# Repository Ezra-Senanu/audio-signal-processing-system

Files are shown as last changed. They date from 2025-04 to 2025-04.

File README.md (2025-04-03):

# Audio Signal Processing System – Treble & Bass Control, Mixer, and Microphone Preamp

## Project Overview

This project implements an Audio Signal Processing System designed to process audio signals with dynamic equalization features such as treble and bass control, as well as mixing multiple audio inputs and amplifying microphone signals. The goal of this project is to provide precise tonal adjustments, combine multiple audio sources with minimal distortion, and amplify microphone inputs with clear signal integrity.

### Key Features:
- **Treble and Bass Control**: Dynamic audio equalization for tonal adjustments.
- **Mixer Circuit**: Combines multiple audio signals while minimizing distortion.
- **Microphone Preamp Circuit**: Amplifies microphone signals for optimal gain control.
- **PCB Design**: Optimized for minimal interference and efficient power distribution.
- **SPICE Simulation**: Validates and optimizes frequency response and circuit behavior.

## Project Components

1. **Treble and Bass Control Circuit**  
   - Designed to adjust the high and low frequencies of the audio signal for dynamic sound shaping.

2. **Mixer Circuit**  
   - Combines multiple audio signals while maintaining signal integrity and minimizing distortion.

3. **Microphone Preamp Circuit**  
   - Amplifies microphone signals for optimal clarity and gain control, ensuring high-quality audio capture.

4. **PCB Design & Layout**  
   - Designed and routed using Altium, ensuring minimal interference and optimal signal quality.
  
5. **Simulation**  
   - SPICE simulations performed in Altium to validate circuit performance and optimize frequency response.

## How It Works

1. **Audio Signal Input**: The audio signals (e.g., from an audio source or microphone) are input into the system.
2. **Treble & Bass Adjustment**: The treble and bass control circuit allows the user to adjust the tonal balance of the audio signal.
3. **Mixing**: The mixer combines multiple audio signals into one, maintaining a clear and balanced output.
4. **Amplification**: The microphone preamplifier amplifies any microphone input signals to a suitable level.
5. **Output**: The final mixed and amplified audio signal is output to speakers or recording devices.

## Getting Started

### Prerequisites:
- **Hardware**:  
  - Audio source(s) (e.g., microphone, line-in signals)
  - Amplification components
  - PCBs and components for assembly (Altium files available)
  
- **Software**:  
  - **Altium Designer**: For PCB design and SPICE simulation.
  - **Embedded Systems IDE**: For firmware development and system integration.

###Altium Project
  -Link
  ```bash
   https://365.altium.com/files/4EA10067-0436-4EB5-9764-D52401654ED2

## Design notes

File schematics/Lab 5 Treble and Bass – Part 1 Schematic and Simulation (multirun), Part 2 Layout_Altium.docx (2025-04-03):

Brigham Young University - Idaho

ECEN 299 – Lab 5

Treble and Bass – Part 1 Schematic and Simulation, Part 2 Layout

7/12/2024

Table of Figures

# Lab 5 (Part 1)

Objectives

Design a PCB for the treble & bass equalization circuits for your stereo amplifier system. Prepare Gerber files to be sent to a PCB manufacturer for fabrication. Later in the semester, when the prototypes arrive, you will be prepared to pick components for your circuit and easily measure the circuit’s performance.

# Principles to Be Studied

- Altium simulation and layout software
- Techniques to simplify debugging.

# Background

Most stereo systems have some sort of equalization, with a tone control adjustment for bass, treble, and perhaps a few mid-band adjustments as well. The design for this lab will allow you to boost (amplify) or cut (attenuate) the bass and treble frequencies by selecting specific capacitor values that allows you to control at what frequency to start boosting or cutting. Although there are many companies to choose from, we will likely use JLCPCB. JLCPCB is a manufacturer in China. You can get good quality boards for a very low price.

# Available Components

Item | Mft Part No. | Manufacturer | Description
1 | LF347DT | STMicroelectronics | IC QUAD OPAMP JFET 4MHZ 14SOIC
2 | 929834-01-36-RK | 3M | CONN HEADER 36POS SNGL .100 STR
3 | Miscellaneous capacitors/resistors, sizes 0603 – 1206

Table 1: Available Components

# Procedures

Figure 1 shows the overall configuration of the stereo system you are currently developing. It includes the left and right channels with the bass and treble filter circuits you are designing in this lab.

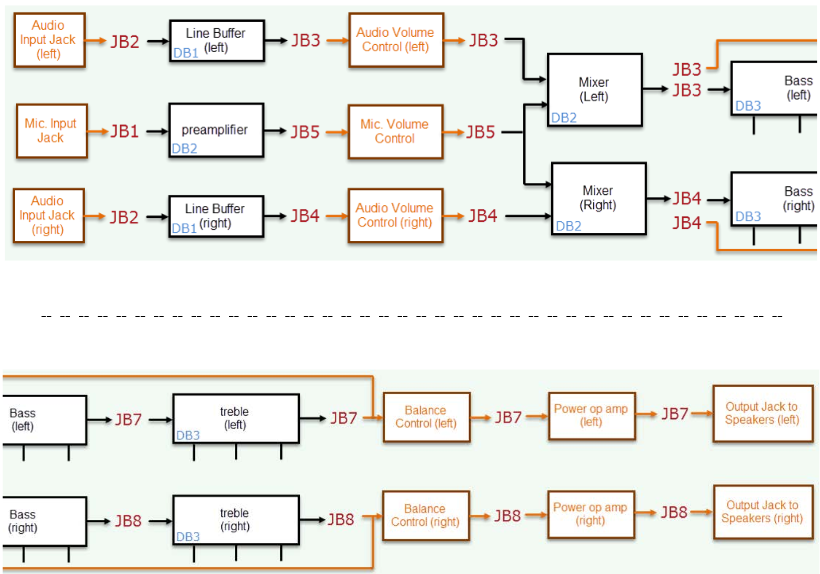
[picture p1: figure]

Figure 1 – Stereo System (Right and Left Channel) Block Diagram Redo Checkmarks.

1. Create a new project in your shared workspace titled Lab5_TB_Lxx_yyy where xx is your lab bench number and yyy are your initials. If you need to review how to do this see lab 4 instructions.
2. Ensure that your projects share dialog box looks like this. See lab 4 instructions or the apendix if you get stuck.

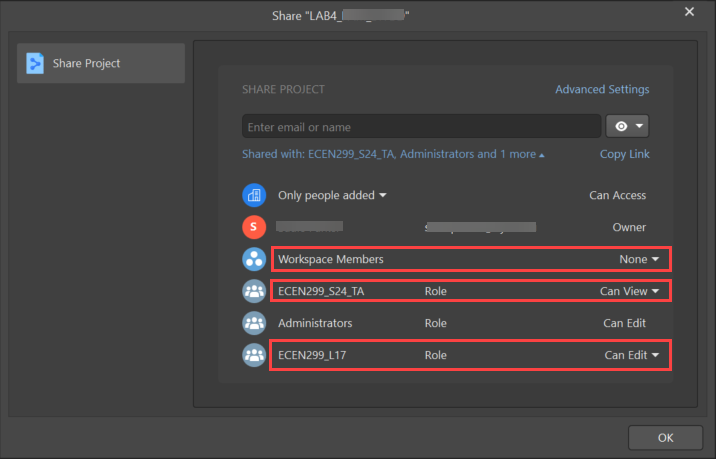
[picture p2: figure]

3. Now just like you did for lab 4, go ahead and create a schematic sheet and PCB Layout Document. Keep the correct name scheme for both documents (Lab5_Sheet1.SchDoc and Lab5_PCB1.PcbDoc)
4. Ensure everything is saved locally and to the Server (look for the green check mark specified in lab 4)

# Create a Symbol for the 23 Pin Header

These instructions are pretty much identical to the lab 4 instructions but the names, number of pins, and footprint will be different.

1. Select Panels > Project (if not already open).
2. Right click Project Group 1.DsnWrk.
3. Select Add Existing Project.
4. Browse to C:\Users\<…>\Desktop\ECEN299\ECEN299_Library
5. Select ECEN299_Library.LibPkg.
6. Select Open.
7. Double click on ECEN_Library.SchLib.
8. Select Panels > SCH Library.
9. Select Add.
10. Type ‘23 Pin Header’ for the Design Item ID.
11. Click OK.
12. In the SCH Library Panel, select 23 Pin Header.
13. Select Tools > Symbol Wizard.
14. Enter 23 for the Number of Pins.
15. Select ‘Single in-line’ as the Layout Style.
16. Enter the pin names in the Display Name column and select the Electrical type as per the figure below.

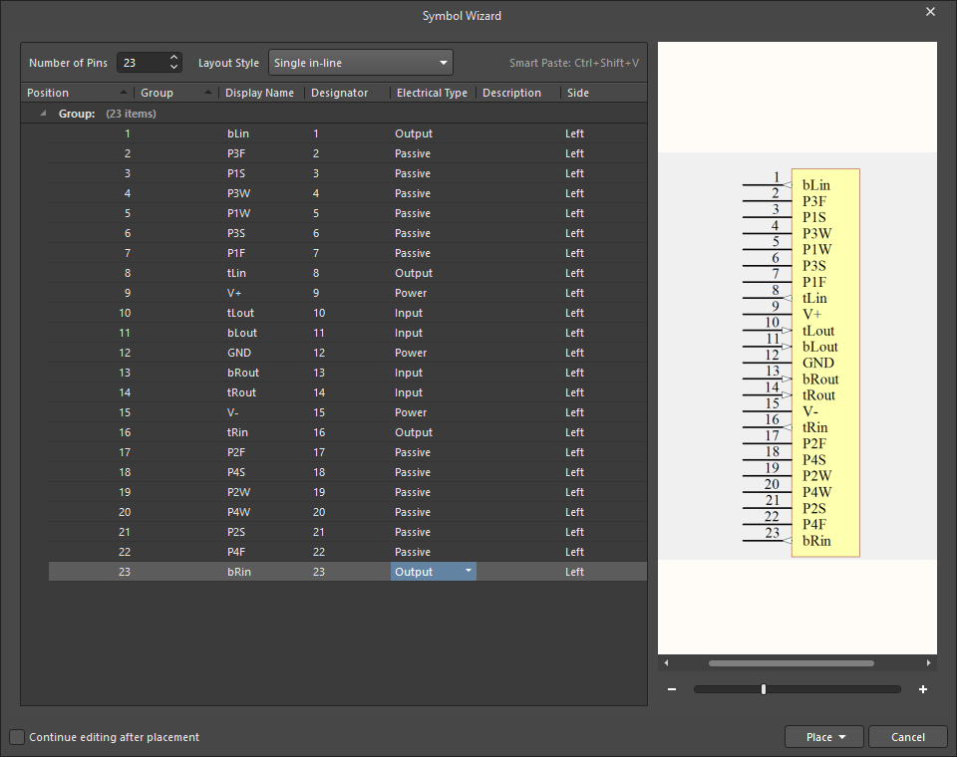
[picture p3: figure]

17. Select Place > Place Symbol.
18. In the Properties window, under Parameters, ensure that 'Footprints' is selected (highlighted in blue), then click on Add... > Footprint.
19. Click on Browse and select KBS_23pin_Header_TB_EQ.

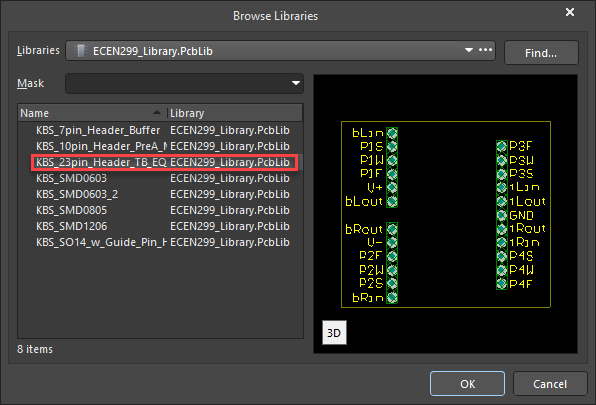
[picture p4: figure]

20. Select OK.
21. Select Pin Map and verify accuracy. (Make sure to verify all 23 pins match!)
22. Select OK to close Model Map
23. Select OK to close PCB Model.
24. In the Properties window, under Parameters, click on Add... > Simulation.
25. Select 'Browse' and locate your DONOTHINGSPICEMODEL.CIR file, which was created in Lab 2 (refer to Lab 2 if needed). Then select Open and OK.
26. In the Projects Window, right click ECEN299_Library.SchLib and select Save.
27. Right click ECEN299_Library.LibPkg and select Compile Integrated Library…
28. Save your Project.
29. In panels navigate to SCH Library. You should now see the 23 Pin Header included among the other Design Item ID’s shown here.

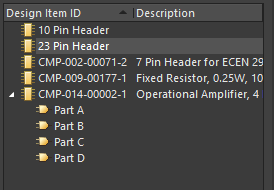
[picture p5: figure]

# Create a Symbol for the Capacitors

1. Select Panels > SCH Library.
2. Select Add.
3. Type CMP-Capacitor for the Design Item ID
4. Click OK.
5. Double-click on CMP-Capacitor to open its properties if they are not already open.
6. In the Properties panel, set the following settings as shown below.

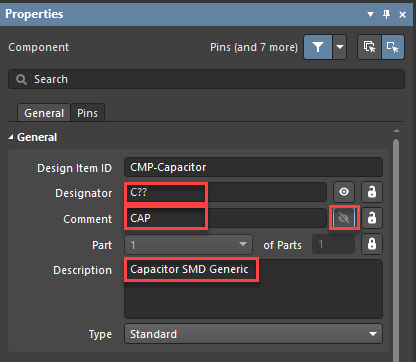
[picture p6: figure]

7. Press the g key to cycle through grid spacing. Stop on Grid: 10mil. To see the current grid spacing look at the bottom left of the program.
8. Select Place > Pin.
9. Press the ‘Tab’ key to change the properties of the pin.
10. Set the following properties as shown below for the first pin.

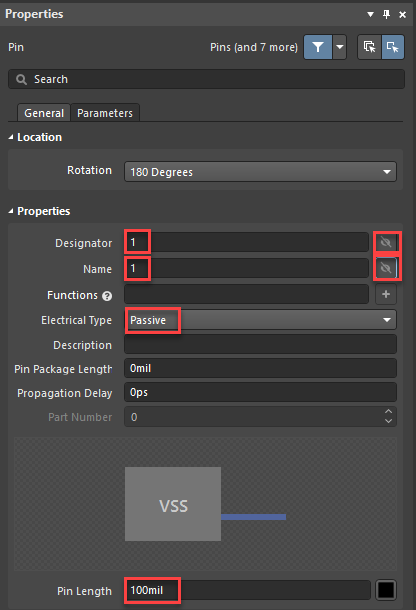
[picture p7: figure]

11. When placing the pin, ensure the designator points outward from your symbol, as it will be used to connect your capacitor to other components/sources.
12. Place the first pin at X: -100mil and Y: 0mil.
13. Place the second pin at X: 200mil and Y: 0mil (Note: you will need to flip the pins orientation to point the designator outwards).
14. Right click to exit placing a pin. Select Place > Line.
15. Press the ‘Tab’ key to change the properties of the Line.
16. Change the line color to blue.

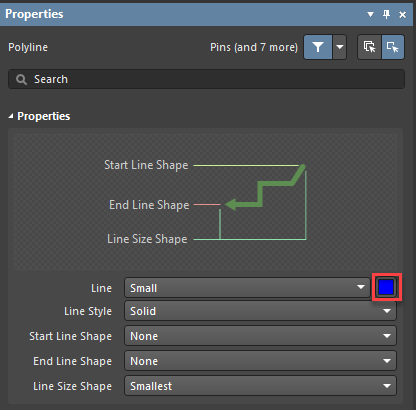
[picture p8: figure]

17. Click the Pause button in the middle of the screen.
18. Start drawing a horizontal line from X: 0 mil, Y: 0 mil to X: 30 mil, Y: 0 mil.
19. Then, draw a vertical line from Y: 80 mil to Y: -70 mil at X: 30 mil.
20. Draw another horizontal line from X: 100 mil, Y: 0 mil to X: 70 mil, Y: 0 mil.
21. Then, draw another vertical line from Y: 80 mil to Y: -70 mil at X: 70 mil.
22. Then, select SCH Library > CMP-Capacitor
23. If the Properties panel is not opened for the CMP-Capacitor, select Panels > Properties.
24. Next, choose Add... > Parameter.
25. Double-click 'Parameter' and rename it to 'Value.'
26. Double-click '*' and set the capacitor's default value to 3.3n.
27. Make the value visible by clicking on the eye icon.
28. Click on Add… > Footprint.
29. Click on Browse and select KBS_SMD0603
30. Select OK.
31. Repeat steps 27 to 29 to add the KBS_SMD0805 and KBS_SMD1206 footprints.
32. Select Add… > Simulation.
33. Select 'Capacitor' for the Model Type.
34. Select OK.
35. In the Projects Window, right click ECEN299_Library.SchLib and select Save.
36. Right click ECEN299_Library.LibPkg and select Compile Integrated Library…

## Designing the Treble and Bass

Figures 2 and 3 illustrate one channel of the bass and treble filter circuits you will design and implement in your stereo amplifier system. You will need to duplicate the circuits in both figures for the left and right channels. Ensure that every resistor, potentiometer, and capacitor has a unique designator.

Note that bLpot and tLpot, Fig. 2 and Fig. 3, are located on the chassis but you need them for simulation purposes.

1. To get the potentiometer, select Components > Simulation Generic Components. Then look for potentiometer in the search field.

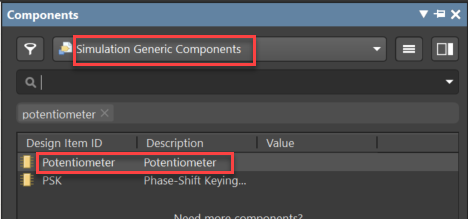
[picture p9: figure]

2. In the Properties panel of the potentiometer, rename the Designator field as needed (e.g., bLpot for the bass left channel) and set the value to 10k, matching the potentiometers already mounted in your chassis.

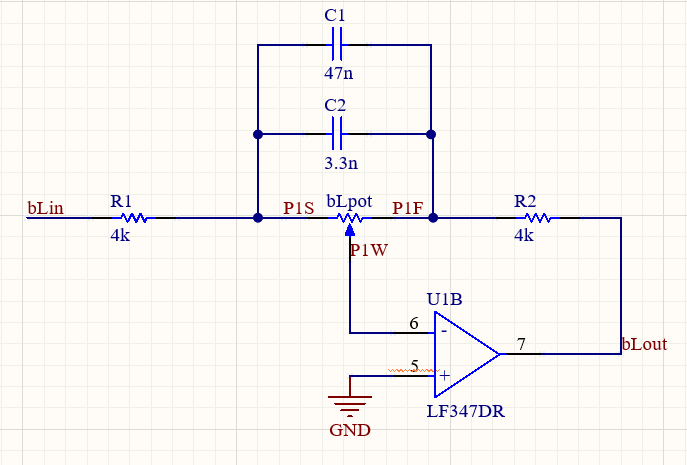
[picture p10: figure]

Figure 2 – Bass Tone Control (one channel)

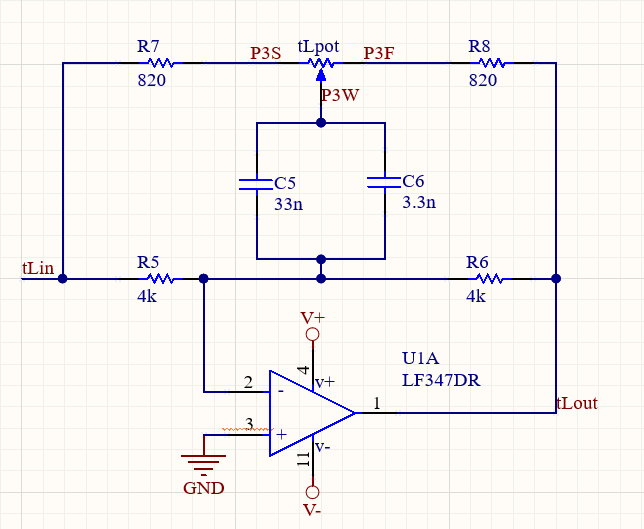
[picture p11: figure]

Figure 3 – Treble Tone Control (one channel)

Table 2 provides the signal names and pin numbers for the 23-pin header. Be careful to label your nets correctly. Miss labeled nets is one of the most common problems in layouts.

Table 2 Signal Names and Pin numbers for the 23-pin header.

Signal Name | Pin # | Description
bLin | 1 | Left channel Bass input
bRin | 23 | Right channel Bass input
P1S | 3 | Source impedance side pot terminal for bass (L)
P2S | 21 | Source impedance side pot terminal for bass (R)
P1W | 5 | Wiper terminal for bass pot (L)
P2W | 19 | Wiper terminal for bass pot (R)
P1F | 7 | Feedback impedance side pot terminal for bass (L)
P2F | 17 | Feedback impedance side pot terminal for bass (R)
P3S | 6 | Source impedance side pot terminal for treble (L)
P4S | 18 | Source impedance side pot terminal for treble (R)
P3W | 4 | Wiper terminal for treble pot (L)
P4W | 20 | Wiper terminal for treble pot (R)
P3F | 2 | Feedback impedance side pot terminal for treble (L)
P4F | 22 | Feedback impedance side pot terminal for treble (R)
bLout | 11 | Left channel Bass output
bRout | 13 | Right channel Bass output
tLin | 8 | Left channel Treble input
tRin | 16 | Right channel Treble input
tRout | 14 | Right channel Treble output
tLout | 10 | Left channel Treble output
V+ | 9 | Positive power rail
V- | 15 | Negative power rail
GND | 12 | Ground

## PCB Tester Compatibility

Verify that your design is compatible with the PCB Tester that was created at BYU-Idaho that can check for shorts and opens in your PCB after it is fabricated. To be compatible with the tester, assign the op amps in your circuit using the instructions in Fig 4.

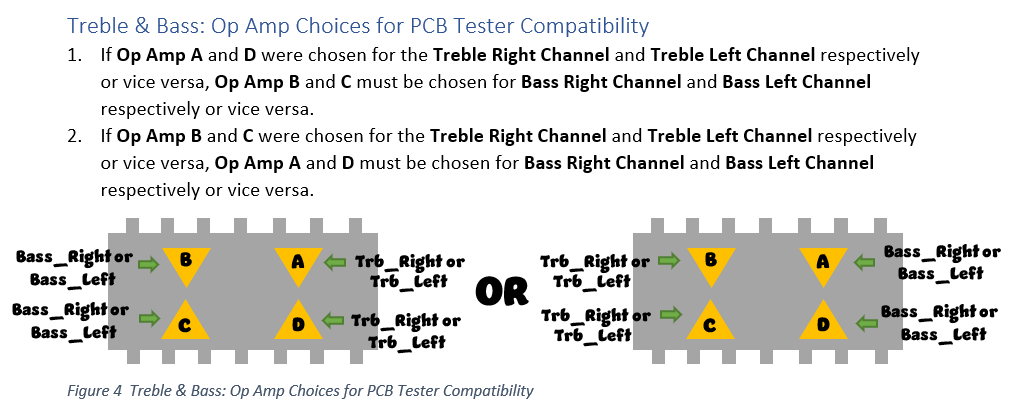
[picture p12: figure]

Figure 4 – Op Amp Selection Guild for compatibility with PCB Tester

# Calculate Expected Bass and Treble Gains

The circuit design allows you to either boost or cut low or high frequencies within the audible range. Let’s calculate the expected gain for both the bass and treble circuit at low and high frequencies and for the control knobs turned all the way down and all the way up.

When analyzing the potentiometer in the context of the circuit, you need to split it into separate resistors, as shown in Fig. 5. The value of α corresponds to the wiper position within the potentiometer. When α=1 , the knob is turned fully clockwise. When α=0 , the knob is turned fully counterclockwise. When α=0.5 , the knob is at the center position.

Figure 5 – Equivalent Potentiometer Circuit

# Bass

The gain equation (also called the transfer function H(jω)=V_(out) /V_(in) ) for the bass circuit and components values needed to meet the design specifications are shown in Appendix A. Using Appendix A Summary and Worksheet, evaluate the gain of the circuit at ω→0 and ω→∞ with the potentiometer set position at α=0 (cut) and α=1 (boost) and record these values in Table 3. Note that at these two frequencies, the capacitor impedance can be replaced with either an open ( ω→0 ) or short ( ω→∞ ) circuit.

Table 3 Bass Filter Circuit Frequency Response Calculations.

|H(jω)|=(ω_n)/(ω_d)(√(1+(ω/(ω_n))^2))/(√(1+(ω/(ω_d))^2)) | ω→0 | ω→∞
α=0 | |H(jω)|_(α=0, ω=0) = | |H(jω)|_(α=0, ω=∞) =
α=1 | |H(jω)|_(α=1, ω=0) = | |H(jω)|_(α=1,ω=∞)

|H(jω)|_(dB) =20log_10 |H(jω)| | ω→0 | ω→∞
α=0 | |H(jω)|_(dB) = | |H(jω)|_(dB) =
α=1 | |H(jω)|_(dB) = | |H(jω)|_(dB) =

How does this analysis support the claim that the circuit will act as a bass tone control?

Use the component values derived in Appendix A. The potentiometer R_2 =10 kΩ is already mounted in your chassis. Simulate this circuit in Altium Designer to verify that you get the desired frequency response.

## Simulate the Circuit

1. Create two DC sources into your schematic: one set at +14 volts and the other at -14 volts to supply power to the Op-Amp.
2. Add a Sinusoidal source to bLin with an AC Magnitude of 1 V.

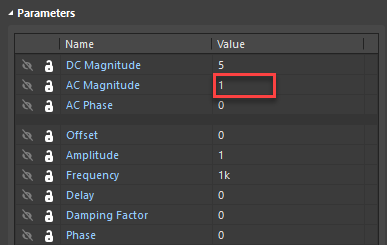
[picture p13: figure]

3. Select Simulate > Simulation Dashboard.
4. To set up parametric sweep for the bLpot potentiometer, select Sweep and then click on Settings.
5. Enter the following Sweep parameters values:
6. Select OK.
7. Create a Frequency Analysis by expanding the AC Sweep section.
8. Set Start Frequency to 20 and End Frequency to 20k.

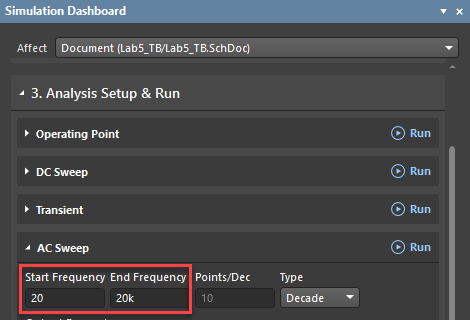
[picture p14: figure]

9. Add bLout as your Output Expression. Ensure the complex functions are set to Magnitude (dB) as shown below when adding the output expression.
10. Select Create.
11. Select Simulate > Run Simulation
12. In the Top Menu, select Simulate > Generate Netlist.
13. Find the Sweep line:
14. Modify the line to add [position] after bLpot.

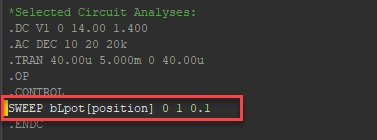
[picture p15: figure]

15. Select Simulate > Run. If it does not open, check Panels > Messages for any error messages.

Figure 6 and Figure 7 plot the typical frequency responses you can achieve with this circuitry. Each curve in the plot represents a different setting of the bass or treble control. Notice that they can be set for a flat (no boost or cut) response.

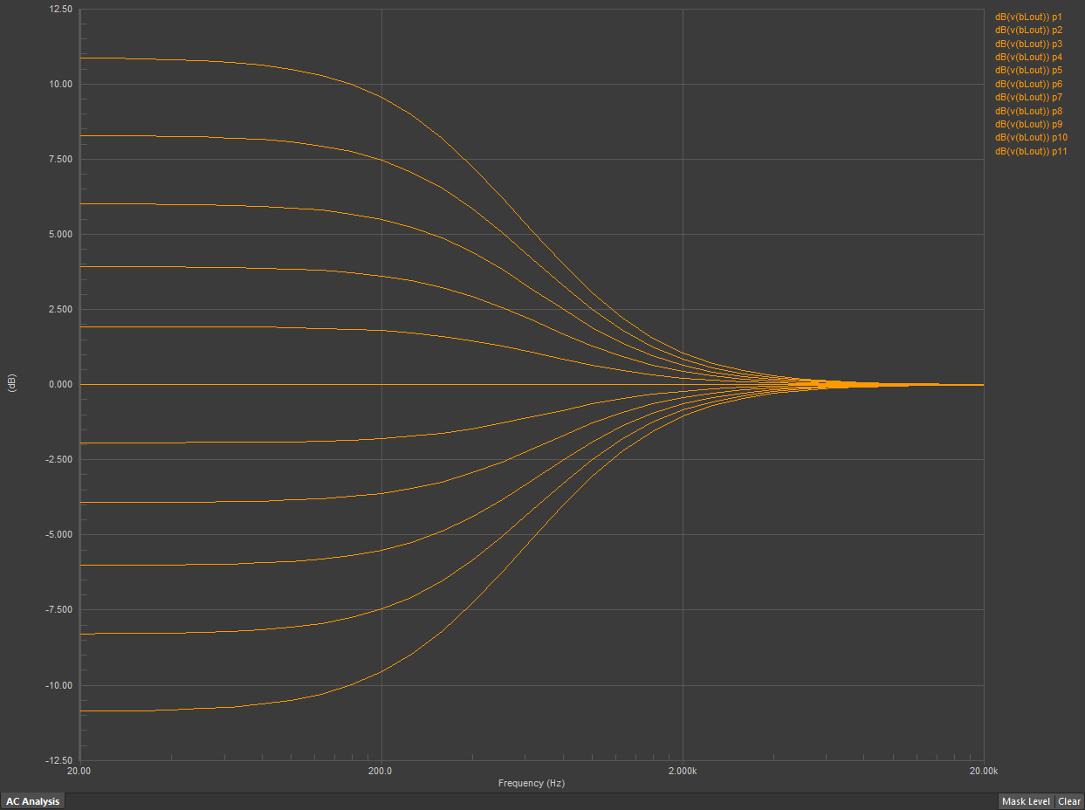
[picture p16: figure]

Figure 6 – Bass Control Frequency Response

# Treble

We will now develop a more detailed analysis of the circuit performance that will help us complete the design. For a maximum boost setting, A_v =1 when ω→∞ and A_v ≫1 when ω→0 .

The gain equation (also called the transfer function H(jω)=V_(out) /V_(in) ) for the treble circuit is shown in Appendix B and is derived by using KCL to sum the currents into each of the potentiometer nodes.

Using Appendix B Summary and Worksheet, evaluate the gain of the treble circuit at ω→0 and ω→∞ with the potentiometer set position at α=0 (cut) and α=1 (boost) and record your results in Table 4. At these two frequencies, the capacitor impedance can be replaced with either an open ( ω→0 ) or short ( ω→∞ ) circuit.

Table 4 Treble Filter Circuit Frequency Response Calculations.

|H(jω)|=(|1+(jω)/(ω_n)|)/(|1+(jω)/(ω_d)|)=(√(1+(ω/(ω_n))^2))/(√(1+(ω/(ω_d))^2)) | ω→0 | ω→∞
α=0 | |H(jω)|_(α=0, ω=0) = | |H(jω)|_(α=0, ω=∞) =
α=1 | |H(jω)|_(α=1, ω=0) = | |H(jω)|_(α=1, ω=∞) =

|H(jω)|_(dB) =20log_10 |H(jω)| dB | ω→0 | ω→∞
α=0 | |H(jω)|_(dB) = | |H(jω)|_(dB) =
α=1 | |H(jω)|_(dB) = | |H(jω)|_(dB) =

How does this analysis support the claim that the circuit will act as a treble tone control?

## Simulate the Circuit

You will now simulate this circuit in Altium Designer to verify that you get the desired frequency response.

1. Add a Sinusoidal source to tLin with an AC Magnitude of 1 V
2. Delete the previous Output Expression (dB(v(bLout)).
3. Add tLout as your Output Expression. Ensure the complex functions are set to Magnitude (dB).
4. Change the Sweep Parameter from bLpot to tLpot as shown below.

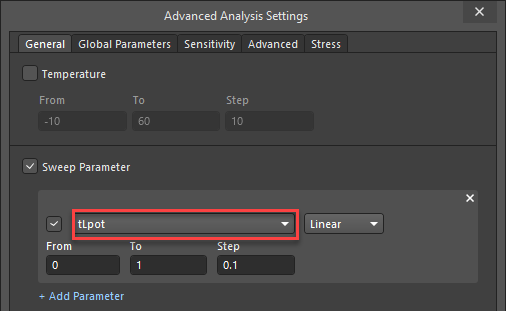
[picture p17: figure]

5. Follow steps 11-15 from the previous Bass Section to complete the simulation.

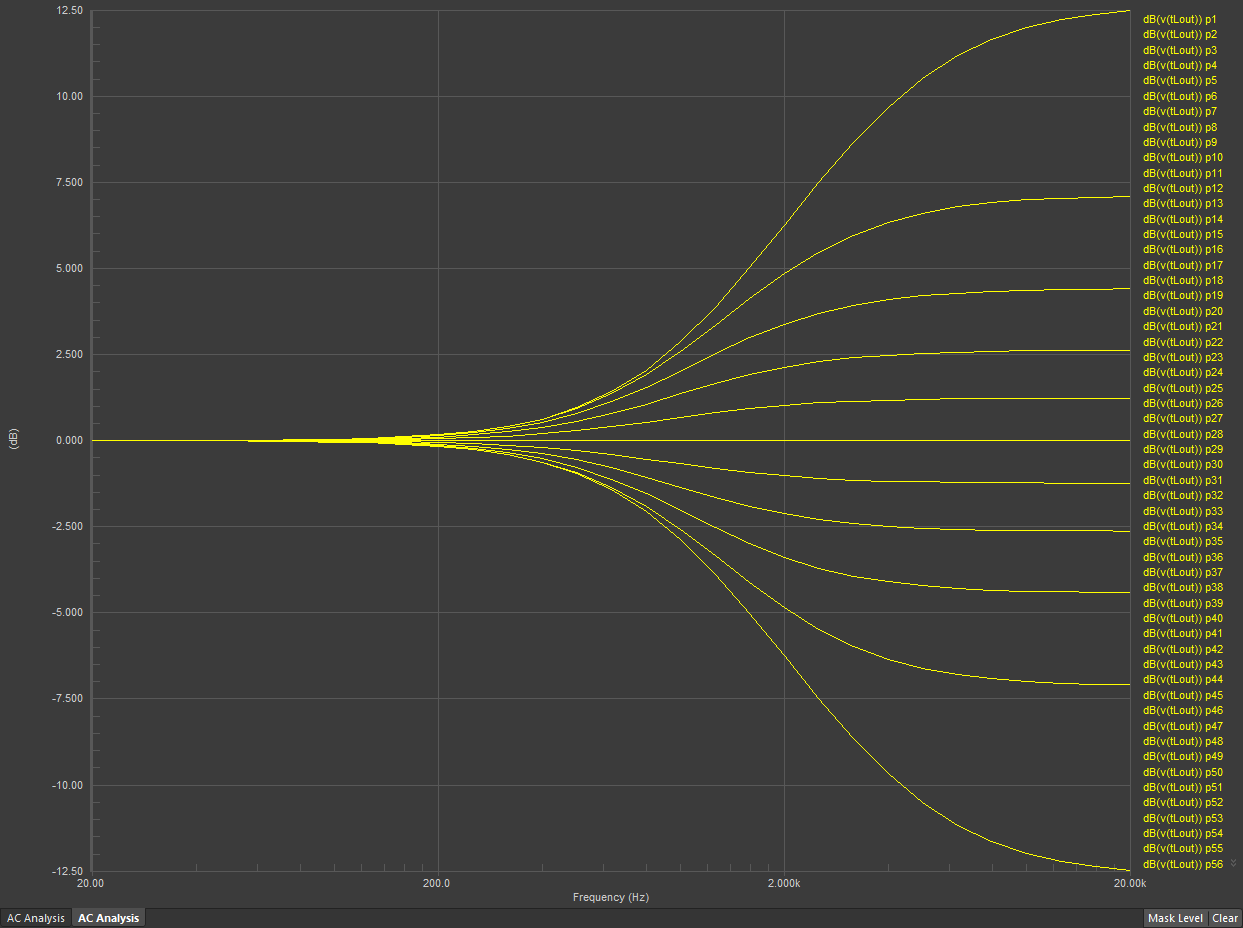
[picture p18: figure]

Figure 7 – Treble Control Frequency Response

Take screenshots of both simulations and add them to your lab report.

Have a lab assistant or the professor check your schematic before moving on to Layout. Include in your lab report who checked your schematic.

# Lab 5 (Part 2)

# PCB Layout

For any questions on how to create a layout, see the previous labs.

The figure below shows the maximum dimensions for the board outline for the Mixer PCB to fit into the chassis. The figure is not to scale. Smaller is typically better for ease of inserting the header pins, but the maximum values should not be exceeded.:

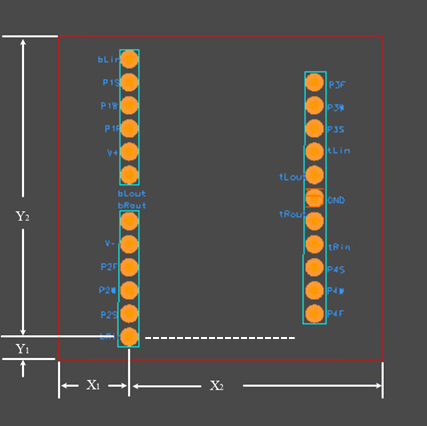
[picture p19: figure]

Y_1 =0.150 in. max., Y_2 =1.400 in. max., X_1 =0.450 in. max., X_2 =1.150 in. max.

- 5 Extra Credit Points for traces on one side and ground plane on other. (Including research on what a ground plane is. The extra credit will be given when your write-up is included in Lab 9).

As in previous labs, zip your Gerber and NC drill files. If you want to check these files with Gerbv, see document called “How to Grade Layouts” (It is getting updated right now from pads to Altium) attached to Lab 4 and Lab 5 (This is how the TA’s grade your PCB’s).

Go to https://jlcpcb.com/ and upload your Gerber files. Make sure they look correct. Take screenshots of this and add them to your lab report.

The grading rubric can be found on I-Learn. If your board contains errors that we catch, you will be asked to correct those errors and resubmit before your board will be fabricated.

Submit your Gerber and NC drill files as a single zip file with your given names as the file name. You will not submit a lab report now since it will be incorporated later when you submit your Lab 9 written lab report.

# Things to remember for Lab 5:

- Take notes of the things you did wrong in Lab 4 and try to avoid making those same mistakes!
- Use the correct Library. That will help you to make sure you are using the correct parts with the correct Footprints and Symbols.
- Set your trace, via and clearance constraints correctly, and do it before routing. That will help you to keep a clearance of 10 mils between your pads and traces.
- Don't place your text or reference designators on resistor pads, header pin pads, op-amp IC pads, or vias. There is no problem with placing your text or references designators over your traces.
- Make sure your text and reference designator sizes are correct. The height of the text should be 40 mil and the width, 6 mil. If you make it too small or narrow, JLCPCB says that your characters will be unidentifiable.
- When you generate your Gerber files, make sure they have the content they are supposed to have. If you have questions about how to check your Gerber files, you can ask a Lab Assistant. You can also download Gerbv at http://gerbv.geda-project.org/. This program allows you to view all your Gerber files separately.
- Make sure that your zip file contains both Gerber and NC Drill files.
- Make sure that the footprints of your resistors, Op Amp and capacitors look alright. (i.e use that right footprint size according to your lab kit)
- Make sure that your board size and the distance between your header pins and your board outline are correct. You can use the Distance tool to measure your distances by using Ctrl M
- Remember to add a ground plane.
- Remember to include the names of both lab partners on your board (On the Top Overlay layer).
- Check that all your header pins are connected to their respective resistors by looking at your schematic along with your layout at the same time. If some of your header pins aren't connected to any resistors or anything, that means some of your connections in your schematic weren't made correctly. Check for components that are not connected properly or for paths that have the same name or reference designator. You shouldn't have repeated path names.

Once your Lab 5 layout is complete, you can use this checklist of things to remember above and the rubric to verify that you have met these requirements.

## Grading Rubric

Grading Rubric
Worth | Description
15 | Overall Board Quality Layout looks organized and clean, conservatively saves board space, utilizes both sides of the board, cells and ref. des. were placed purposefully.
15 | Reference designators are present, descriptive, and placed appropriately
15 | Correct Trace Widths (10 mils)
15 | Size Constraint Is within the allowed maximum dimensions.
10 | 10-pin header is placed within allowed limits of the board outline
10 | All Gerber files are present and have correct content. The NC Drill file (.ncd) shows drill holes lining up with holes, vias, and header pins.
10 | Include the names of each group member on the board
5 | Hole, Vias, and Cells correctly sized
5 | NC Drill (.ncd) file in the same folder as the other Gerber files.
100 | Total

# Appendix A – Bass Transfer Function and Selecting Component Values

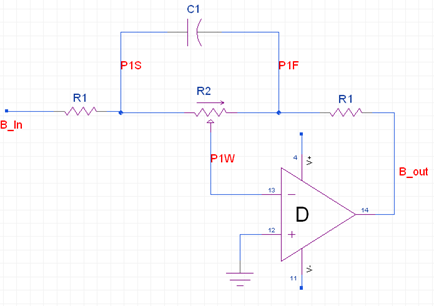
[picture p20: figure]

The transfer function for the bass circuit is derived in the textbook on page 606 (11ed) as

H(s)=(V_o)/(V_i)=-(R_1 +αR_2 +R_1 R_2 C_1 s)/(R_1 +(1-α)R_2 +R_1 R_2 C_1 s).

This can be rewritten as

H(s)=(V_o)/(V_i)=-(((R_1 +αR_2 ))/((R_1 +(1-α)R_2 ))(1+s/((R_1 +αR_2)/(R_1 R_2 C_1))))/((1+s/((R_1 +(1-α)R_2)/(R_1 R_2 C_1)))).

Thus, the Bass Transfer function can be written as

H(s)=(V_o)/(V_i)=-(ω_n)/(ω_d)((1+s/(ω_n)))/((1+s/(ω_d)))

where

ω_n =(R_1 +αR_2)/(R_1 R_2 C_1),

ω_d =(R_1 +(1-α)R_2)/(R_1 R_2 C_1).

From this transfer function, we can solve for component values that will meet the specifications.

1. To meet the specification of |H(jω)|_(dB) ≥+10 dB at high frequency with α=1 , then

|H(jω)|ω→0, a→1= lima=1(ω_n)/(ω_d)= (R_1 +R_2)/(R_1) ≥10^(10/20) =3.2.

Since R_2 =10 kΩ ,

R_1 ≤(R_2)/(3.2-1)=10000/2.2=4.55 kΩ.

Therefore, let R_1 =4.1 kΩ.

2. To meet the specification of |H(jω)|_(dB) =+3 dB at ω=ω_c =2π(1000)(rad)/s with a = 1, then

ω_n ≅ω_c . That is

ω_n |_(a=1) = (R_1 +R_2)/(R_1 R_2 C_1) ≅2π(1000)(rad)/s

C_1 ≅(R_1 +R_2)/(R_1 R_2 2π(1000))=(4100+10000)/((4100)(10000)2π(1000))=55 nF.

Therefore, let

C_1 =52 nF.

Nominally, this will set the corner frequency to

f_n |_(a=1) = (R_1 +R_2)/(R_1 R_2 C_1 2π)= (4100+10000)/(4100(10000)(55×10^(-9) )2π)=1014 Hz.

## Appendix A Summary and Worksheet - Bass Transfer Function:

H(s)=(V_o (s))/(V_i (s))=-(ω_n)/(ω_d)((1+s/(ω_n)))/((1+s/(ω_d)))

where

ω_n =(R_1 +αR_2)/(R_1 R_2 C_1),

ω_d =(R_1 +(1-α)R_2)/(R_1 R_2 C_1).

R_2 =10 kΩ

R_1 =4.1 kΩ

C_1 =52 nF

| ω_n =(R_1 +αR_2)/(R_1 R_2 C_1)
α=0 | ω_n |_(α=0) =
α=1 | ω_n |_(α=1) =

| ω_d =(R_1 +(1-α)R_2)/(R_1 R_2 C_1)
α=0 | ω_d |_(α=0) =
α=1 | ω_d |_(α=1) =

|H(jω)|=|-(ω_n)/(ω_d)((1+(jω)/(ω_n)))/((1+(jω)/(ω_d)))|=(ω_n)/(ω_d)(|1+(jω)/(ω_n)|)/(|1+(jω)/(ω_d)|)=(ω_n)/(ω_d)(√(1+(ω/(ω_n))^2))/(√(1+(ω/(ω_d))^2))

|H(jω)|=(ω_n)/(ω_d)(√(1+(ω/(ω_n))^2))/(√(1+(ω/(ω_d))^2)) | ω→0 | ω→∞
α=0 | |H(jω)|_(α=0, ω=0) = | |H(jω)|_(α=0, ω=∞) =
α=1 | |H(jω)|_(α=1, ω=0) = | |H(jω)|_(α=1,ω=∞)

|H(jω)|_(dB) =20log_10 |H(jω)| | ω→0 | ω→∞
α=0 | |H(jω)|_(dB) = | |H(jω)|_(dB) =
α=1 | |H(jω)|_(dB) = | |H(jω)|_(dB) =

# Appendix B - Treble Transfer Function and Selecting Component Values

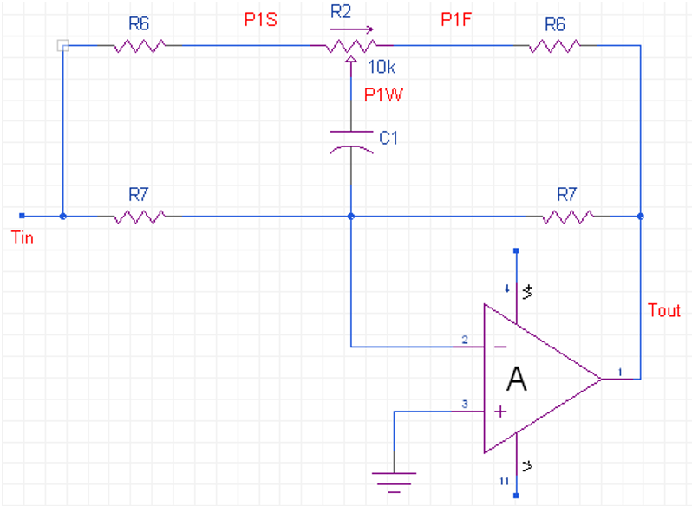
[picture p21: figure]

1. The transfer function for the Treble Amplifier Circuit, shown above, is

(V_o (s))/(V_(in) (s))= - (1+ s/(ω_n))/(1+ s/(ω_d)), where ω_n = (2R_6 + R_2)/(C_1 (R_6 +aR_2 )(R_6 +R_7 +(1-a)R_2 )), ω_d = (2R_6 + R_2)/(C_1 (R_6 +(1-a)R_2 )(R_6 +R_7 +aR_2 )). | Eqn. 11

From this transfer function, we can solve for component values that will meet the specifications.

1. To meet the specification of |H(jω)|_(dB) ≥+12 dB at high frequency with a = 1, then

|H(jω)|ω→∞, a→1= lima=1(ω_d)/(ω_n)= ((R_6 +R_2 )(R_6 +R_7 ))/((R_6 )(R_6 +R_7 +R_2 )) ≥4.0.

Thus,

((R_6 +R_2 )(R_6 +R_7 ))/((R_6 )(R_6 +R_7 +R_2 ))≥4.0.

2. To meet the specification of |H(jω)|_(dB) =+3 dB at ω=ω_c =2π(1000)(rad)/s with a = 1, then

ω_n ≅ω_c . That is

ω_n |_(a=1) = (2R_6 + R_2)/(C_1 (R_6 +R_2 )(R_6 +R_7 )) ≅2π(1000)(rad)/s

These two constraints can then be used to find values for R_6 ,R_7 , and C_1 that will meet desired specifications

From the first constraint,

R_6 (R_6 +R_2 )+R_7 (R_6 +R_2 )≥4.0(R_6 )(R_6 +R_2 )+4.0(R_6 )R_7

(R_6 +R_2 -4.0R_6 )R_7 ≥4.0R_6 (R_6 +R_2 )-R_6 (R_6 +R_2 )

R_7 ≥(3.0R_6 (R_6 +R_2 ))/((R_2 -3.0R_6 ))

Letting R_2 =10 kΩ and R_6 =820 Ω , yields

R_7 ≥(3.0R_6 (R_6 +R_2 ))/((R_2 -3.0R_6 ))=(3.0(820)(820+10000))/((10000-3.0(820)))=3.53 kΩ

Thus, let R_7 =4.1 kΩ .

From the second constraint,

C_1 ≅ (2R_6 + R_2)/(2π(1000)(R_6 +R_2 )(R_6 +R_7 ))= (2(820)+ 10000)/(2π(1000)(820+10000)(820+4100))=35 nF.

Thus, let C_1 =36 nF.

Reference only: The potentiometer R_2 =10kΩ is already mounted in your chassis. Resistors R_5 and R_7 allow for necessary input bias current (http://www.analog.com/static/imported-files/tutorials/MT-038.pdf). To understand how R_5 and R_7 affect the circuit, redraw it with the capacitor either shorted or open (depending on the frequency) and the potentiometer drawn as shown in Figure 5.

## Appendix B Summary and Worksheet - Treble Transfer Function

### Treble Circuit

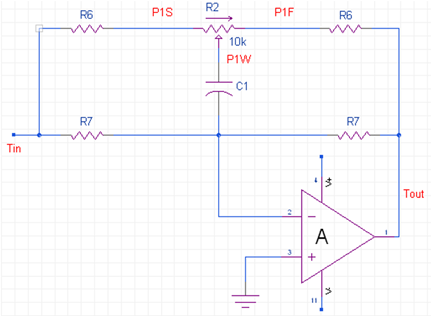
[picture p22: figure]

Treble Transfer Function:
(V_o (s))/(V_(in) (s))=-(1+s/(ω_n))/(1+s/(ω_d)),

where

ω_n =(2R_6 +R_2)/(C_1 (R_6 +aR_2 )(R_6 +R_7 +(1-a)R_2 )),

ω_d =(2R_6 +R_2)/(C_1 (R_6 +(1-a)R_2 )(R_6 +R_7 +aR_2 )).

and

R_2 =10 kΩ

R_6 =820 Ω

R_7 =4.1 kΩ

C_1 =36 nF.

| ω_n =(2R_6 +R_2)/(C_1 (R_6 +aR_2 )(R_6 +R_7 +(1-a)R_2 ))
α=0 | ω_n |_(α=0) =
α=1 | ω_n |_(α=1) =

| ω_d =(2R_6 +R_2)/(C_1 (R_6 +(1-a)R_2 )(R_6 +R_7 +aR_2 ))
α=0 | ω_d |_(α=0) =
α=1 | ω_d |_(α=1) =

|H(jω)|=(|1+(jω)/(ω_n)|)/(|1+(jω)/(ω_d)|)=(√(1+(ω/(ω_n))^2))/(√(1+(ω/(ω_d))^2))

|H(jω)|=(|1+(jω)/(ω_n)|)/(|1+(jω)/(ω_d)|)=(√(1+(ω/(ω_n))^2))/(√(1+(ω/(ω_d))^2)) | ω→0 | ω→∞
α=0 | |H(jω)|_(α=0, ω=0) = | |H(jω)|_(α=0, ω=∞) =
α=1 | |H(jω)|_(α=1, ω=0) = | |H(jω)|_(α=1, ω=∞) =

|H(jω)|_(dB) =20log_10 |H(jω)| dB | ω→0 | ω→∞
α=0 | |H(jω)|_(dB) = | |H(jω)|_(dB) =
α=1 | |H(jω)|_(dB) = | |H(jω)|_(dB) =

## Appendix C

## Edit Shared with Project Options

Share with

1. Select Panels > Explorer.
2. Select Folders tab at the bottom.
3. Expand the ECEN299_S24 > Lxx folder where xx is your lab bench number.
4. Select your Lab4_PAM_Lxx_yyy project.
5. Select Share.

### Share with ECEN299_Lxx = Can Edit

6. Expand Shared with.
7. Select Remove next to Workspace Members.
8. Enter ECEN299_Lxx in the Enter email or name field.
9. Select ECEN299_Lxx (role).

This is a role that is assigned to you and your lab partner.

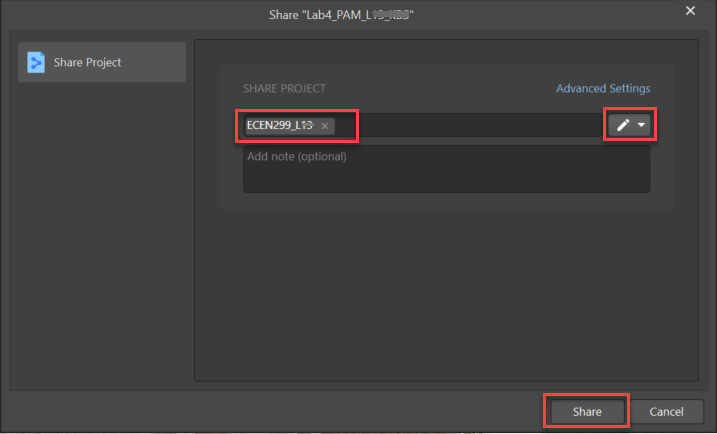
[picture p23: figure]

10. Select the eye icon and select Can Edit.
11. Select Share.

### Share with Workspace Members = Remove (None)

12. Select Who has access.
13. Select Can Edit for ECEN299_Lxx (if not already selected).
14. Select Remove for Workspace Members.

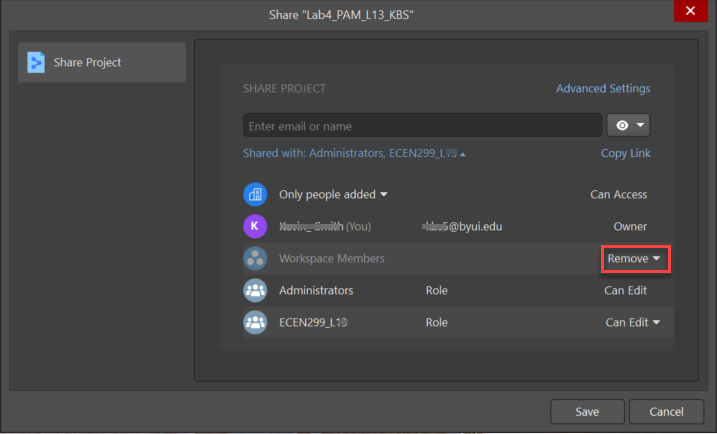
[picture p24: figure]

This will permit only you and your lap parent to edit the project.

15. Select Save.

### Share with ECEN299_S24_TA = Can View

16. Select Who has access.
17. Enter ECEN299_S24_All in the Enter email or name field.
18. Select ECEN299_S24_All (role).
19. Select the eye icon and select Can View. (if not already selected)
20. Select Share.

The Share dialog box should look like this:

21. Select OK to close Share “Lab4_PAM_Lxx_yyy”.

## To Open Your Lab Partner’s Workspace Project

1. Open Altium Designer.
2. Sign in and select a license.
3. Select the BYUI Workspace server (top left).
4. Select Panels > Projects.
5. Select File > Open Project.
6. Select the pulldown menu next to Open.
7. Select Open to custom path.
8. Browse to %UserProfile%\Desktop\ECEN299.
9. Click Select Folder.

The Project is copied locally and is linked to the server.

ECEN 299 – Lab 5 Treble and Bass – Part 1 Schematic and Simulation, Part 2 Layout

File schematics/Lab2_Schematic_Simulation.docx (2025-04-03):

# Lab 2 Schematic and Simulation

## Prerequisite

1. Complete Lab 1.
2. If the project for Lab 1 is not already open in Altium Designer then follow these steps.
  a. Select Windows Start > Altium Designer.
  b. If not already done, open the Projects panel (View > Panels > Projects).
  c. Verify that ECEN299_Library.PcbPkg is open. (If not, open it.)
  d. Verify that Lab1_Buffer.PrjPcb is open. (If not, open it.)

## Background

The circuit that will be built is shown in Figure 1. It is called an inverting amplifier circuit, and it is being used as a buffer circuit. It is called a buffer circuit because the inputs Lin and Rin will always see 10 kΩ regardless of what the outputs Lout and Rout are attached to. The Left output voltage, Lout, is calculated as

V_(Lout) (t)=-(R_2)/(R_1)V_(Lin) (t)=-(30k)/(10k)V_(Lin) (t)=-3.0V_(Lin) (t).

This equation holds when the Op Amp is not saturated. Saturation occurs if the output is being driven to a value outside of the supply voltages. That is, the output voltage is bounded by

V_(-) =-14 V≤V_(Lout) (t)≤V_(+) =+14 V.

For example, if V_(Lin) =2.0 V, then V_(Lout) =-3.0∙2.0 V=-6.0 V. On the other hand, if V_(Lin) =7.0 V, then the calculated value is V_(Lout) =-3.0∙7.0 V=-21.0 V , However, before it reaches that value the Op Amp will go into saturation which holds V_(Lout) to roughly - 14 V.


Figure 1 Buffer Circuit Schematic

## Set Schematic Preferences

1. Open preferences by selecting the gear icon in the top right corner.

Note: to open documentation on a topic, select any topic in the preferences and hit F1.

2. Open the Schematic > General Options section.
3. Select Display Cross-Overs.

Now arcs will be displayed where wires cross but are not connected.

4. Open Schematic > Graphical Editing section.
5. Select Always Drag.

This will keep wires attached to a symbol while moving the symbol around.

Hold the control button down before moving the symbol to temporarily toggle between modes. Click Apply to save the new preferences.

## Set up the Grid.

If you accidentally use a small grid, it can be extremely difficult to see if wires are currently tied to a component without zooming in very far. And this could lead to a lot of accidental opens in your productivity.

1. Double click Buffer_Sheet1.SchDoc so it is open and select View>Panels > Properties.
2. Expand the General tab. Note: Your Properties panel changes based on what you are currently working on. For example, if you have a component selected, this panel will show you the properties of that component. So, in this case you should have the Buffer_Sheet1.SchDoc open.
3. Enter Visible Grid as 100mil.
4. Enter Snap Grid as 200mil.

Note: Any grid value can be entered using the Properties panel. Using the hotkey G, you are limited to the 3 options of 10, 50, 100 that are set up in Preferences > Schematic > Grids.

# Place Components on the Schematic

1. Double click Buffer_Sheet1.SchDoc in the Project panel to open it.

### Set Grid

2. Press the g key to cycle through grid spacing. Stop on Grid: 100mil. To see the current grid spacing look at the bottom left of the program.
3. Select View>Panels > Components if the panel is not already open.
4. To place the components on your Buffer_Sheet1.SchDoc shown in Figure 1, select Components panel.
5. Double Click on CMP-014-00002-1 to select the Op-Amp. The Op-Amp should follow your cursor. Before placing the Op-Amp in the schematic sheet, press the Tab key to open the properties of your selected component.
6. Change the Designator from U?? To U1, and then click on the pause button to exit the Properties panel of the Op-Amp.


7. Place the Op-Amp by left-clicking anywhere in the Buffer_Sheet1.SchDoc and press the Tab key again before placing the second Op-Amp.
8. In the properties panel, select Part D for the second Op-Amp and then click on the pause button to exit the Properties panel. (Note: The first op amp was automatically assigned PartA)


9. Place the Second Op-Amp and then press the Esc key to exit.
10. In the Components Panel, double click on the CMP-009-00177-1 to place the resistor. Before placing the resistor, press the Tab key and change the Designator from R?? To R1.


11. Click on the pause button to exit the Properties panel of the resistor and start placing the resistors as shown in Figure 1. Notice that the designators of the resistors start increasing as they are being placed.
12. To change the resistance value for R2 and R4, click on the value of the resistor.
13. Change the resistance value in the Properties Panel


14. In the Components Tab, double-click or drag the CMP-002-00071-2 to place the 7 Pin Header.
15. Make sure to change the Designator of the 7 Pin Header from *? To U2.
16. To connect your components with wires, click the double-blue wavy line (Which is the wire tool) as shown below.
17. Click on the place you want to start then click again where you want to end the wire. When you are finished with the wire tool, you can either right click or press the escape button. Hint: A shortcut to create a wire without using the wire tool is by dragging a component next to the one you want to connect to until the leads touch. Then, drag them apart, and a wire will be created.
18. To add a ground to your schematic, click on the ground symbol and click to place it.
19. To place a circle style power port for V+ and V-, right-click on the ground symbol and select 'Place Circle style power port’ as shown below.


20. Make sure to change the names to match V+ and V-. (If you need to flip the power port just type 270 in the degrees option when you hit tab)
21. Add net labels by right clicking the wire tool and selecting the net label as shown. Note: Net Labels are the labels on the 7-pin header and wires. This shows where the 7-pin header connects to the components in the schematic. For example, Lin is the left input which will connect to R1. So, we place a net label, Lin, on the 7-pin header and where we want the input to go, in this case the left side of R1.


22. Click to place. Right click or press escape to exit.
23. Then rename the net label by clicking on it. Then under Net Name change it to be the name specified in the schematic. (The net labels in the schematic are Lin, Lout, Rin, Rout, GND, V+, and V-) note: All the labels on the 7pin header are net labels. Those net labels will connect to the ground symbols and the Circle style power ports. For example, the GND net label on the 7-pin header will connect to the ground symbol placed on the positive lead of the Op-Amp. Likewise, the two power ports V+ and V- will connect to the net labels V+ and V-.
24. Select File > Save All.

# Align Components to the Grid

If the components get placed off grid, they may be difficult to wire together. Follow these steps to align the components back to the grid.

1. Type g to cycle the grid resolution to the desired value.
2. Select all the components on the schematic.
3. Select Edit > Align > Align To Grid.

# Set Up for Simulation

# Install Extension (Mixed Simulation)

1. Start Altium Designer.
2. Sign in.
3. Select User Icon (top right).
4. Select Extensions and Updates.
5. Select Purchased Tab.
6. Hover over Mixed Simulation
7. Select the download icon that appears. If already downloaded, it will show a check mark as shown below.
8. Select OK to restart Altium Designer message.
9. Close Altium Designer.
10. Start Altium Designer.

## Place Voltage Sources

1. Select Simulate tab > Place Sources > Voltage Source.
2. Create two DC sources, one at +14 volts and the other at –14 volts as shown in the image below on the left.
3. Create two Sinusoidal sources both at 1 amplitude and a frequency of 1k as shown below on the right.


The DC Magnitude parameter value is used when running an Operating Point analysis.

The AC Magnitude parameter value is used when running an AC Sweep (or frequency) analysis.

The Amplitude parameter value is used when running a Transient analysis.

4. As shown in the schematic below add ground labels to the newly created voltage sources as previously explained (see place components on the schematic step 18)
5. Add circle style power ports to each voltage source with names as the schematic below specifies. (For a reminder see place components on the schematic step 19)


Include a screenshot of your Buffer_Sheet1.SchDoc schematic sheet in your lab report.

## Assign Simulation Models to Placed Components

### Resistor Simulation Model

1. Right Click on R1 and select Properties.
2. Expand Parameter.
3. Select Models.
4. Select Add > Simulation.


5. Change the Model Type to Resistor.


6. Change Value from 10k to a desired value.
7. Click OK exit Sim Model.
8. Repeat steps above to add a simulation model to resistors R2, R3, and R4.

### KBS_7pin_Header_Buffer Component

1. Open notepad and create a document with the name DONOTHINGSPICEMODEL.CIR with the following two lines :

.SUBCKT NOTSIMULATED 1

.ENDS NOTSIMULATED

2. Click on the 7-pin header that was previously placed on the schematic.

The Properties window will open.

3. Make sure ‘Models’ is selected in the Parameters section.

Note: The selected Parameters are blue as shown in the picture.

4. Select Add at the bottom of the Parameters section.
5. Select Simulation.
6. Select Local as the Source.
7. Select Browse.
8. Select DONOTHINGSPICEMODEL.CIR. Note: This document is made by you.

This is a text file with the following two lines in it:

.SUBCKT NOTSIMULATED 1

.ENDS NOTSIMULATED

9. Select Open.
10. Select Model File in the Model Description section.

The contents of DONOTHINGSPICEMODEL.CIR are displayed.

11. Update the Pin Mapping as follows.


12. Select OK to close the Sim Model window.

### Op Amplifier with footprint kbs_SO14_w_Guide_Pin_Holes

1. Click on one of the Op-amps previously placed. The properties panel will open.
2. Double-Click on Simulation


3. The Model Name of the Op-Amp should be ‘IDEALOPAMP_5NODES’ as shown below. In case your Op-Amp doesn’t have this Model, refer to Appendix A.


4. Correct Pin Mapping for Part 1/4, Part 2/4, Part 3/4, and Part 4/4.


Select OK to close the Sim Model window.

## Adding Simulation Models to ECEN299_Library.LibPkg

The simulation models can also be added to the components in ECEN_Library.SchLib. The steps are basically the same as described above for place components. As explained in Lab 1, when you are finished modifying the components, right click on ECEN299_Library.LibPkg and select Compile Integrated Library ECEN299_Library.LibPkg. Now, components placed components from the integrated library will now have the assigned models.

## Run Simulation

1. Select Simulate > Simulation Dashboard.
2. Select Start Verification. Note: If your Electrical Rule Check is not a green check, it means your schematic has an issue. For example, a resistor is unconnected.
5. After verification is complete, expand 3. Analysis Setup & Run section in the simulation dashboard.
6. Expand the Transient tab, then click on +Add under the Output Expressions. To add a simulation output for v(Lin), click on the three dots as indicated below. A new window will open. Scroll down until you locate v(Lin), select it, and click on 'Create'.


7. Repeat step 6 for v(Lout), v(Rin), and v(Rout).
8. Assign the left channel to plot 1 and the right channel to plot 2. To create a new plot, open the drop-down menu labeled with the number 1 and choose 'New Plot'. Additionally, consider customizing the plot colors, as they will initially appear gray by default.


9. Select Simulate > Run Simulation.

Lab3_Buffer.sdf will open.

10. Select Transient Analysis Tab at the bottom to see your simulation


11. Go back to the Schematic.
12. Select Simulate > Simulation Dashboard.
13. Expand 3. Analysis Setup & Run.
14. Select Operating > Run.


The window with plots will open.

15. Select Panels > Sim Data.
16. In the Source Data box find v(Lout) then Add Wave to Plot. Repeat this step for v(rin) and v(rout).


17. Go back to the Schematic.
18. Select Simulate > Simulation Dashboard.
19. Expand 3. Analysis Setup & Run.
20. Expand Operating Point.
21. Select Voltage.


Voltage value labels appear on the schematic.

22. Toggle the Power button and the Current button as well to see Power value labels and Current value labels appear on the schematic.

Include a screenshot in your report of the Transient Analysis as shown on Lab1_Buffer.sdf, the Operating point as shown on Lab1_Buffer.sdf, and the circuit with the Voltage value labels turned on as shown on Buffer_Sheet1.SchDoc. Does the design operate as expected? Explain why or why not. Is saturation modeled as expected? Also include the equations for gain using an inverting op-amp configuration. Does the design meet design specifications, based on your simulation?

# DONT FORGET TO SAVE!!!!

1. Select File > Save All.

# Appendix A

1. Select Add in the Parameters section.
2. Select Simulation.
3. Select Library as the Source in the Model Properties section of the Sim Model window.
4. Select Browse.
5. Select Simulation Generic Components.
6. Select Op-Amp with power terminals.
7. Select OK

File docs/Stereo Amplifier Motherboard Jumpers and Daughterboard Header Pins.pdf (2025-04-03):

### Stereo Amplifier: Motherboard Jumpers and Daughterboard Header Pins


== == == == == == == == == == == == == == == == == == == == == == == == == == == == ==

Figure 1 (a) Functional block diagram of Audio Amplifier (Motherboard and Daughterboards)


Figure 1 (b) Stereo Amplifier Motherboard with Jumper Blocks (JB) and Daughterboard (DB) header pins highlighted.


Figure 2 (a) Functional block diagram of Line Buffer Daughterboard DB1.


Figure 2 (b) The two 2-pin and one 3-pin headers for the line buffer daughterboard are defined.


Figure 3 (a) Functional block diagram of Microphone Preamplifier and Mixer Daughterboard DB2.


Figure 3 (b) The 2-pin, 3-pin, and 5-pin headers for the microphone preamplifier and mixer daughterboard are defined.


Figure 4 (a) Functional block diagram of Bass and Treble Control Daughterboard DB3

Figure 4 (b) The two 6-pin and one 11-pin headers for the bass and treble daughterboard are defined.


Figure 4 (c) Traces showing how the bass and treble pots are connected to DB3 header pins


Figure 5 Jumper block JB1 connect the microphone input to the microphone preamplifier.


Figure 6 Jumper block JB2 connect the left and right audio inputs to the corresponding left and right line buffer inputs.


Figure 7 Jumper block JB3 connects (left channel) 1. The line buffer output to the audio volume control input, 2. The audio volume control output to the mixer audio input, 3. The mixer output to the bass control input, and 4. The balance control input can be also be connected (not shown) at this jumper block for debugging purposes.


Figure 8 Jumper block JB4 connects (right channel) 1. The line buffer output to the audio volume control input, 2. The audio volume control output to the mixer audio input, 3. The mixer output to the bass control input, and 4. The balance control input can be also be connected (not shown) at this jumper block for debugging purposes.


Figure 9 Jumper block JB5 connect 1. The microphone volume control output to the mixer microphone input, and 2. The mic. preamplifier output to the microphone volume control input.


Figure 10 Jumper Block JB6 connects the positive and negative supply voltages to the corresponding power op amplifier supply pins. NOTE: BE CAREFUL NOT TO CONNECT THE POSITIVE AND NEGATIVE SUPPLY VOLTAGES TOGETHER (not shown). The next motherboard design will have the two rows of pins spaced farther apart so that a jumper cannot be placed in a way that shorts the power supplies together.


Figure 11 Jumper Block JB7 connects (left channel) 1. The bass control output to the treble control input, 2. The treble control output to the balance control input, 3. The balance control output to the power op amp input, and 4. The power op amp output to the audio output jack.


Figure 12 Jumper Block JB7 connects (Right channel) 1. The bass control output to the treble control input, 2. The treble control output to the balance control input, 3. The balance control output to the power op amp input, and 4. The power op amp output to the audio output jack.


Figure 13 Top and bottom traces on the motherboard.

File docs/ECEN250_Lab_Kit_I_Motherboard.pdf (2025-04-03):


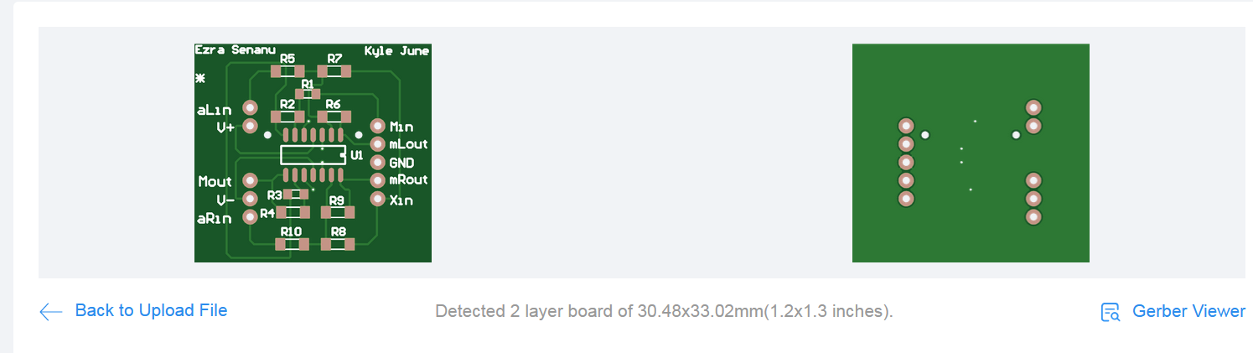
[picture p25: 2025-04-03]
pcb-layout/lab4_JLCPCB_screenshot.png

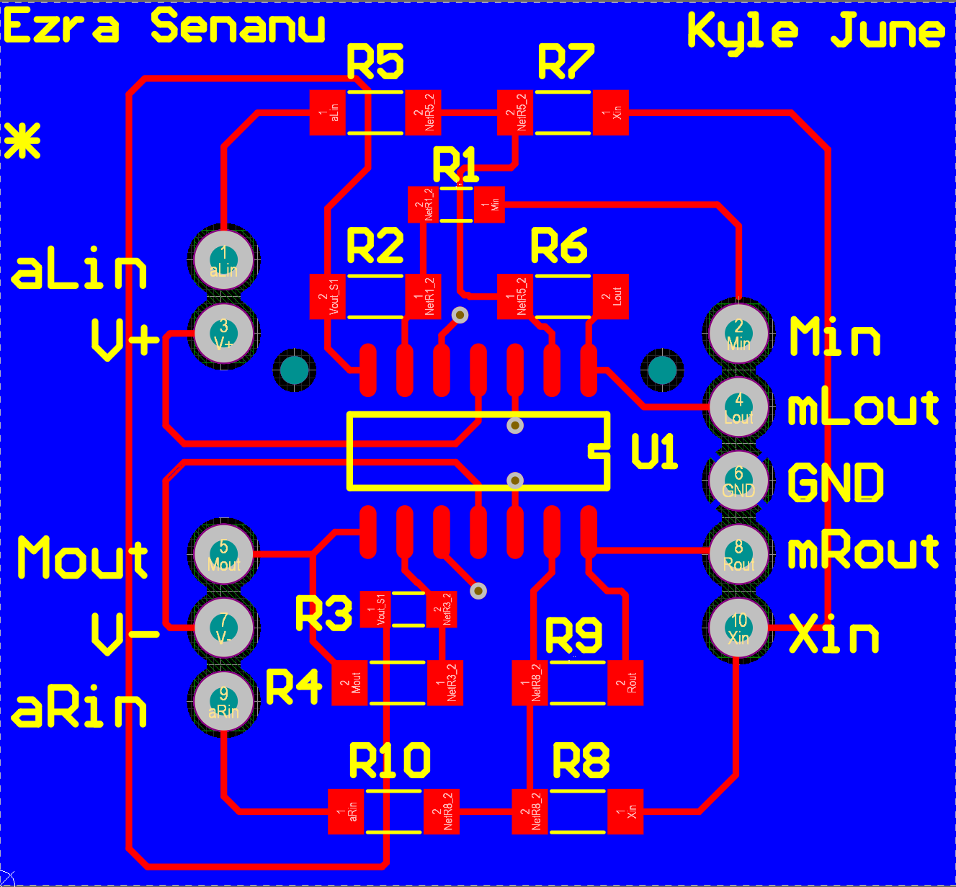
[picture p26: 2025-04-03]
pcb-layout/lab4_PCB_screenshot.png

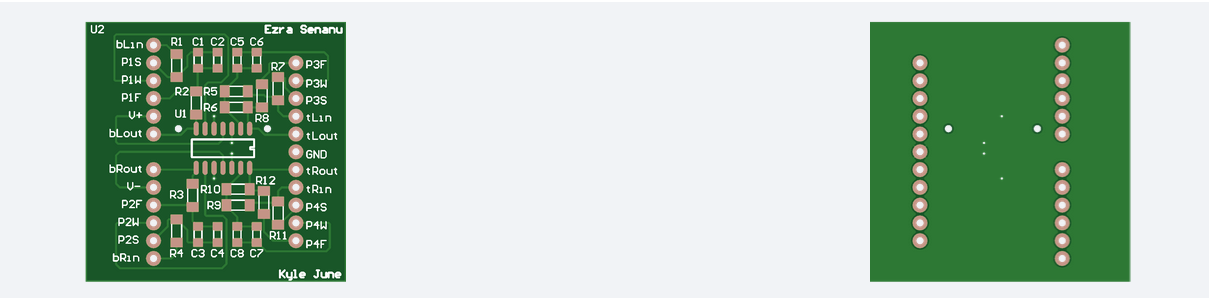
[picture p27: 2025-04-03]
pcb-layout/lab5_JLCPCB.png

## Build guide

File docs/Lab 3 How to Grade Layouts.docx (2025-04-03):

# How to Grade Layouts

# JLCPCB

Upload the zipped Gerber files to the JLCPCB instant quote. (https://cart.jlcpcb.com/quote?orderType=1&stencilLayer=2&stencilWidth=100&stencilLength=100&stencilCounts=5)

Check for first immediate issues that can be caught and that the board is showing up as you would expect it to-

- Silk Screen issues
  - Missing or incorrectly placed reference designators (e.g., overlapping pads or holes)
  - Missing or incorrectly placed names
- No traces or pads being cut off by the edge

# Gerber Viewer

To check all the specific details of the board, go to the C drive and open the folder GerberViewer and click on “gerbv”. Go to File > Open Layer(s) or press Ctrl + O. Navigate to the unzipped Gerber files of the project and open all 8 files: Board_Outline.GKO, Bottom_Layer.GBL, Bottom_Silkscreen.GBO, Bottom_Soldermask.GBS, ThruHolePlated.ncd, Top_layer.GTL, Top_Silkscreen.GTO, Top_Soldermask.GTS.

(Note: The NC Drill file (.ncd) is required to be in the same folder as the other Gerber files)

You can use the zoom tool (Tools > Zoom Tool) to help zoom in right on your board.

Deselect all layers and view each one individually in relation to the other layers.

1) Board Outline
  a) Leave this on as you inspect all other layers and ensure that none of them are outside of this outline.
2) Bottom
  a) Check that the Bottom Soldermask shows up and is over the Bottom Layer header pins
  b) Check that any text on the bottom silkscreen is showing up backwards on the Gerber Viewer (they will show up normal on JLCPCB).
  c) If there are vias these should show up on the bottom layer as well.
  d) There should be no pads on the bottom layer.
3) NC Drill File
  a) Keeping the bottom layer on turn on the NC Drill hole layer. Holes should show up in the center of all header pins and via holes.
  b) If holes are not showing up, right click on the drill file and select Edit File Format. Deselct autodetect and try out different integers in the digits box until your drill holes line up in the center of your header pins and via holes.
4) Size Constraints
  a) Keeping only the board outline and the NC Drill file selected turn on the Top Layer, again ensuring that Drill Holes are still lined up properly.
  b) Using the Measure Tool (Tools > Measure Tool) measure the different constraints on the board according to the Lab document. Measure from the center of the (bottom left) drill hole to the edge of the board outline, see below.

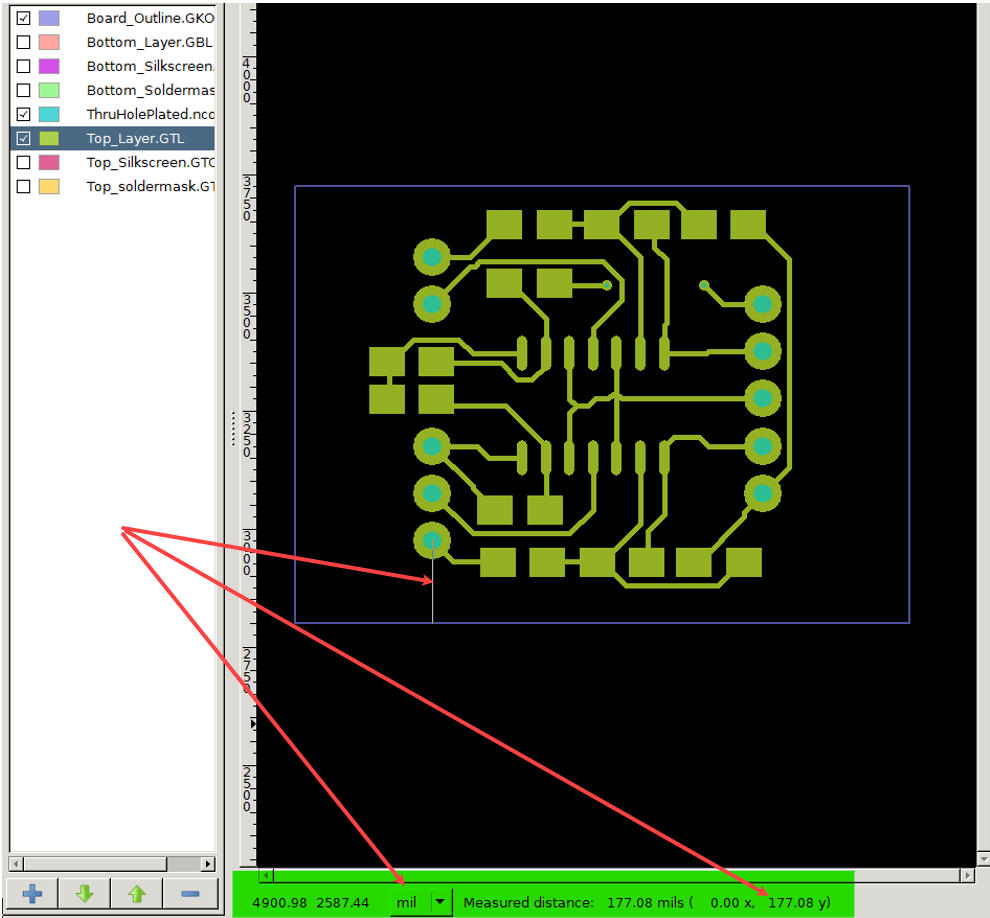
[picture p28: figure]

  c) The measurements can be less than or equal to constraints given to ensure that the daughter PCB will fix in the chassis. However, designing the smallest PCB possible should be the goal. Thus, look for ways to conserve space and decrease the size of the board outline if possible.
5) Top Layer
  a) On the Top Layer measure the traces to ensure they are 10 th.
  b) During the third and fifth labs ensure that pads are correctly sized. (The third lab is the first time using the resistor pads and the fifth is the first time using the capacitor pads from the myCentralLibrary made in Lab 1).
  c) Check that there are traces connected to each component on the board. If there are any components that do not have a trace connected to them, then there is something wrong. Sometimes traces are connected to the header pins from the bottom layer. (Note: Lab 5 if you use a ground plane there will be no traces connected to the ground header pin but it should be connected to the plane.)
6) Top
  a) View the Top Solder Mask and ensure that it is covering all pads and header pins from the top layer.
  b) Leave only the top solder mask and the board outline on, then turn on the Top Silkscreen. Ensure that there is nothing from the silkscreen (reference designators or names) overlapping and getting cut off by pads or header pins.

# Tips for Resubmissions

When editing your board to resolve any issues, be sure to keep a couple of things in mind-

- If you change the position of reference designators, you need to regenerate the silkscreen. Upload to JLCPCB or open in gerbv.exe to make sure any changes you make are reflected there.
- If you change the position of your vias or header pins, then you need to generate a new NC Drill File. If you do not, your drill holes will be in the wrong position.
- If you change the trace widths in your constraint manager, then you will still need to change the trace widths of the traces you have already placed. Under Loc: Routing you can select the whole board, right-click, and update most of the trace widths there. It will not update ones that are in positions where they will no longer fit if they were updated.

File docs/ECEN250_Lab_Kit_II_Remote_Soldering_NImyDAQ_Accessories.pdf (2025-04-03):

Item | Descreption
1 NI myDAQ - Hardware only
2 | Soldering Iron Kit Electronics, 21-in-1, 60W Adjustable Temperature Soldering Iron, 5pcs Soldering Iron Tips, Soldering Iron Stand, Desoldering Pump, Magnifier, Solder Wire, Tweezer, PU Carry Bag

3 PCB Holder - Aven 17010 Adjustable Circuit Board Holder
4 Flux Pen - MG Chemicals Flux Pen Soldering, 2 x 10 mL, Amber
5 | Jumper wires - Elegoo EL-CP-004 60pcs Multicolored Dupont Wire 20pin Male to Female, 20pin Male to Male, 20pin Female to Female Breadboard Jumper Wires Ribbon Cables Kit for arduino

6 Safety Glasses - Gateway Safety 3699 Colorful Starlite Gumballs Safety Glasses, Small, All Colors Included 7 Kimwipes - Kimtech Science Task Wipes Kimwipes KCC34155-06 (Original Version)
8(a) | with Screw On Cap
8(b) | Isopropyl Alcohol - Equate 91% Isopropyl Alcohol Antiseptic (inside Dropper bottle above)
10 Toothbrush - Toothbrush Individually Wrapped Standard Medium Bristle
11 Solder Wick - Chemtronics Desoldering Braid, Chem-Wik, Rosin, 10-50L 0.10", 1ft.
12(a) | Solder - Kester Sn63Pb37 2.2%/245 .020 (2463378834) (on Bobbin below)
12(b) | Bobbin - Class 15 Clear Bobbins Made to Fit Singer 006066008
Componets Needed For Daughter boards | Buffer | Mixer | T&B | Extras | Total
| | | | | per kit | Actual Components Supplied | Qty
LF347DT Op Amp | 1 | 1 | 1 | 3 | 6 | Op Amp (LF347DT) | 6
Header Pins | 7 | 10 | 23 | 40 | 80 | Header Pins (40 Pin Strips) | 2
Resistors | | | | | | Resistors
10 kΩ | 2 | 7 | 5 | 14 | 10 kΩ, 1%, 1/4 W, SMD 0805 | 14
30 kΩ | 2 | 1 | 3 | 30 kΩ, 1%, 1/4 W, SMD 0805 | 3
600 Ω | 1 | 1 | 2 | 600 Ω, SMD 0805 | 2
15 kΩ | 1 | 1 | 2 | 15 kΩ, 1%, SMD 0603 | 2
100 kΩ | 1 | 1 | 2 | 100 kΩ, 5%, 1/8 W, SMD 0805 | 2
4 kΩ | 8 | 4 | 12 | 8.2 kΩ, SMD 1206 | 24 | 8.2 kΩ||8.2 kΩ = 4.1 kΩ
800 Ω | 4 | 2 | 6 | 820 Ω, SMD 1206 | 6
Capacitors | | | | | | Capacitors
55.7 nF | 2 | 1 | 3 | 47 nF, 10%, 50 VDC, SMD 0805 | 3 | 47 nF || 6.8 nF = 54 nF
| | | | | | 6.8 nF, 10%, 50 VDC, SMD 0805 | 3
36 nF | 2 | 1 | 3 | 33 nF, 10%, 50 VDC, SMD 0805 | 3 | 33 nF || 3.3 nF = 36 nF
| | | | | | 3.3 nF, 10%, 100 VDC, SMD 0805 | 3
Daughter PCBs | 1 | 1* | 1* | 0 | 1 | Buffer PCB | 1
* To be designed by students

ECEN 250 Remote Lab Kit: NI myDAQ, Soldering Kit, and Accessories

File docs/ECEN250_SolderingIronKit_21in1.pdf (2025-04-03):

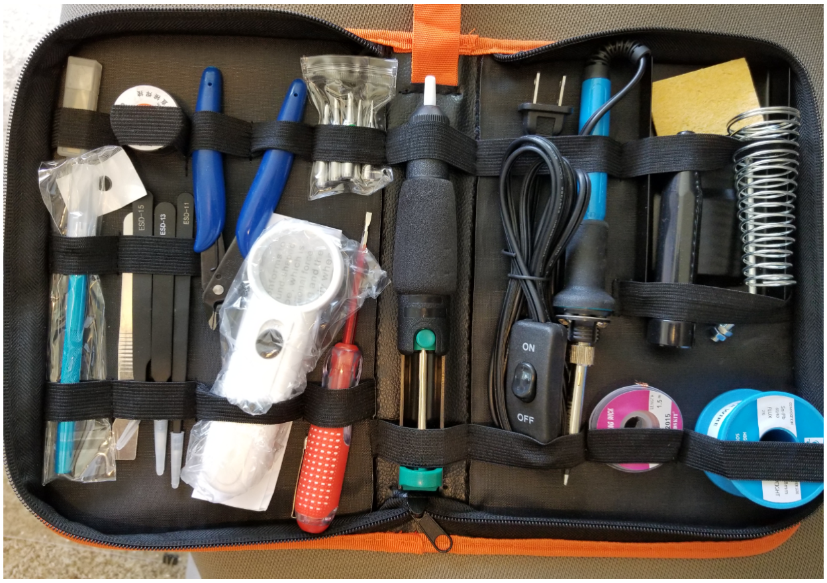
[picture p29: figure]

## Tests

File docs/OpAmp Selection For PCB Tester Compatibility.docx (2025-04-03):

# Op Amp Selection for PCB Tester Compatibility

Refer to Fig. 1 and the instructions below when considering which LF347 Op Amps to use in your ECEN 250 daughter Board designs. Following these instructions will ensure that your choice is compatible with our PCB tester. Although not covered in these instructions, you should also consider which Op Amp selection will best simplify routing traces to the header pins.

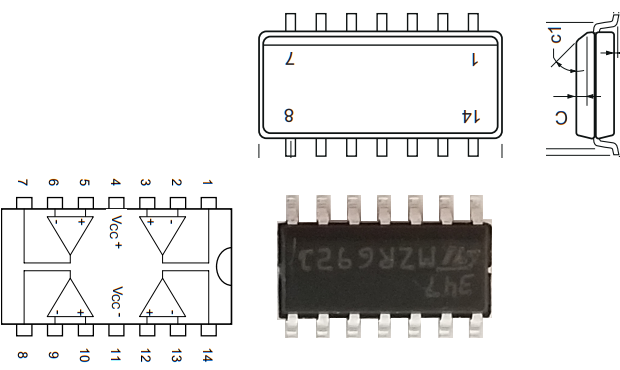
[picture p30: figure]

A

B

C

D

Figure 1 LF347 Quad Package Pinout

## Buffer Amplifier: Op Amp Choices for PCB Tester Compatibility

1. If Op Amp A is chosen for the Right Channel, Op Amp D must be chosen for the Left Channel or vice versa.
2. If Op Amp B is chosen for the Left Channel, Op Amp C must be chosen for the Right Channel or vice versa.

Not used

Not used

Right or Left

Channel

Right or Left

Channel

Not used

Right or Left

Channel

Right or Left

Channel

Not used

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
Figure 2 Buffer Amplifier: Op Amp Choices for PCB Tester Compatibility

## Microphone & Mixer: Op Amp Choices for PCB Tester Compatibility

1. If Op Amp A and D were chosen for the Mic Stage 1 and Mic Stage 2 respectively or vice versa, Op Amp B and C must be chosen for Mixer Right Channel and Mixer Left Channel respectively or vice versa.
2. If Op Amp B and D were chosen for the Mic Stage 1 and Mic Stage 2 respectively or vice versa, Op Amp A and D must be chosen for Mixer Right Channel and Mixer Left Channel respectively or vice versa.

OR

Mic_S1 or

Mic_S2

Mic_S1 or

Mic_S2

Mix_Right or

Mix_Left

Mix_Right or

Mix_Left

Mic_S1 or

Mic_S2

Mic_S1 or

Mic_S2

Mix_Right or

Mix_Left

Mix_Right or

Mix_Left

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
Figure 3 Microphone & Mixer: Op Amp Choices for PCB Tester Compatibility

## Treble & Bass: Op Amp Choices for PCB Tester Compatibility

1. If Op Amp A and D were chosen for the Treble Right Channel and Treble Left Channel respectively or vice versa, Op Amp B and C must be chosen for Bass Right Channel and Bass Left Channel respectively or vice versa.
2. If Op Amp B and C were chosen for the Treble Right Channel and Treble Left Channel respectively or vice versa, Op Amp A and D must be chosen for Bass Right Channel and Bass Left Channel respectively or vice versa.

OR

Trb_Right or

Trb_Left

Trb_Right or

Trb_Left

Bass_Right or

Bass_Left

Bass_Right or

Bass_Left

Trb_Right or

Trb_Left

Trb_Right or

Trb_Left

Bass_Right or

Bass_Left

Bass_Right or

Bass_Left

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
Figure 4 Treble & Bass: Op Amp Choices for PCB Tester Compatibility

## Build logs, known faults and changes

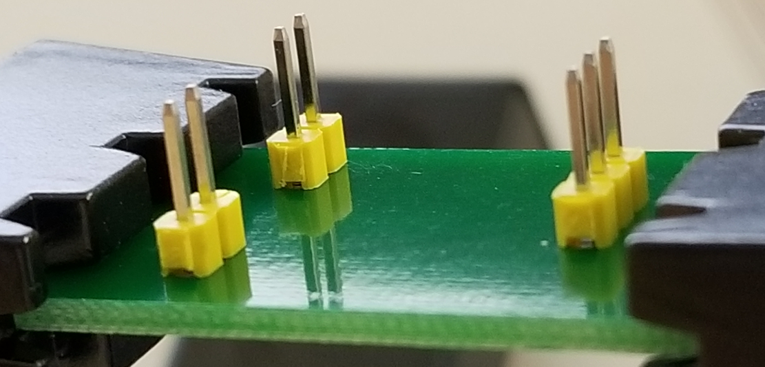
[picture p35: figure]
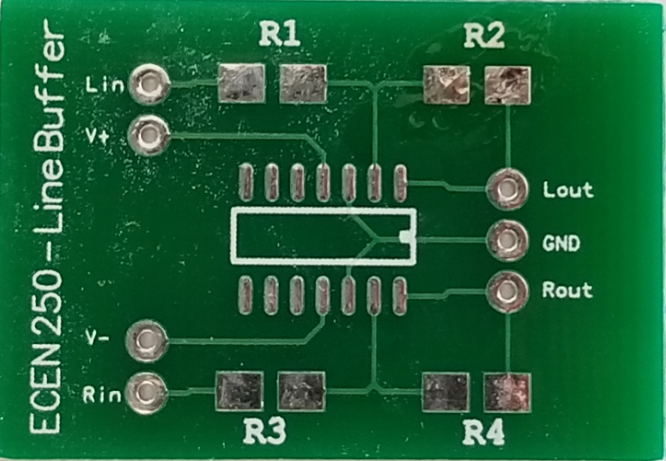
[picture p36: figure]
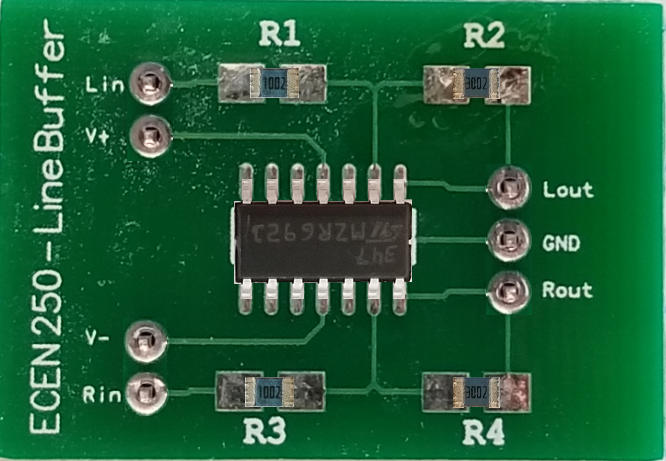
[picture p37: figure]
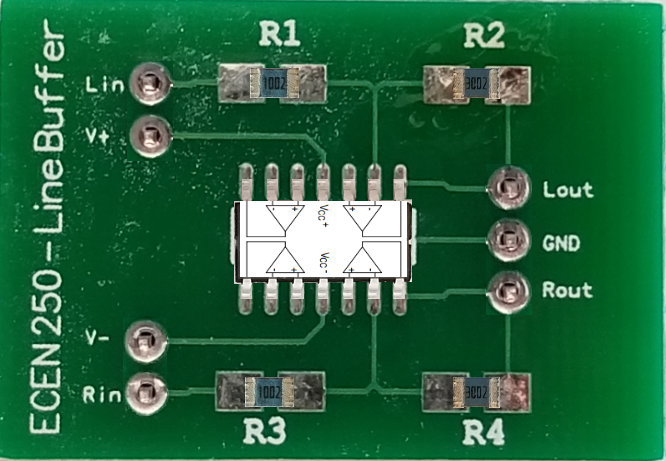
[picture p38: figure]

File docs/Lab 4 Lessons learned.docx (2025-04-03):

Lab 4 Lessons learned from the school of hard knocks.

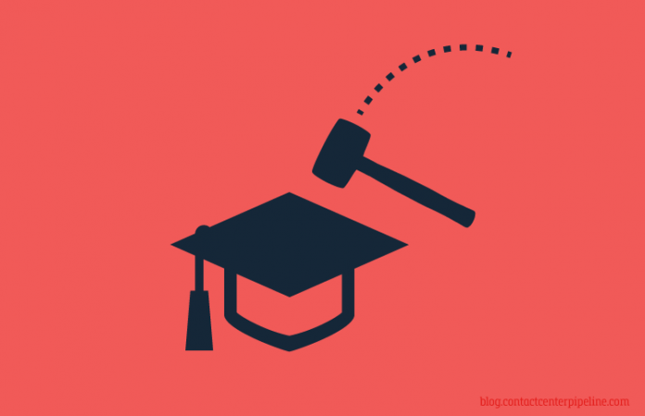
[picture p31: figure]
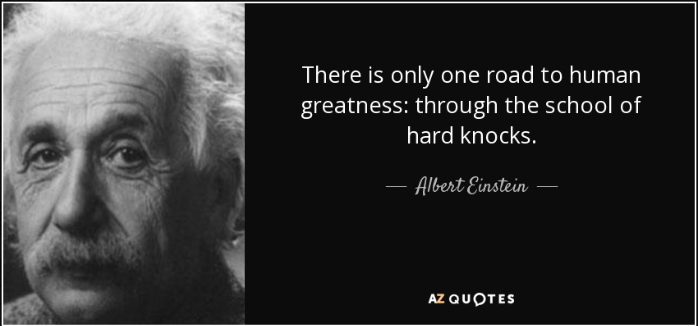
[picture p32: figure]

https://blog.contactcenterpipeline.com/2017/07/the-school-of-hard-knocks-are-you-a-graduate/

https://www.azquotes.com/quotes/topics/school-of-hard-knocks.html

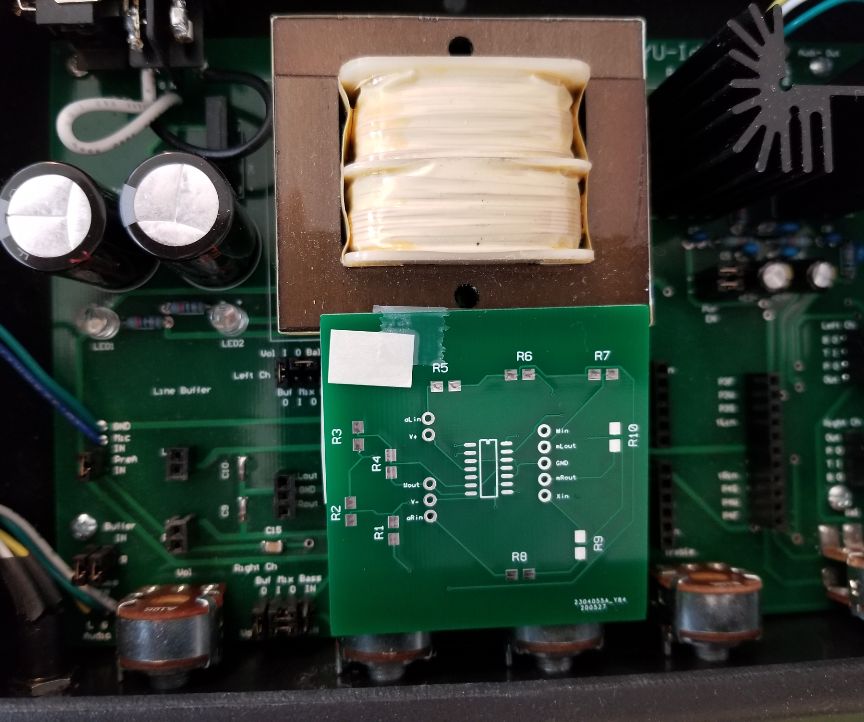
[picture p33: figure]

Figure 1 Outline of this Mixer PCB is 2”x2” which does not fit on the motherboard.

Connecting wires will need to be used for the Mixer PCB headers pins to reach the motherboard headers.

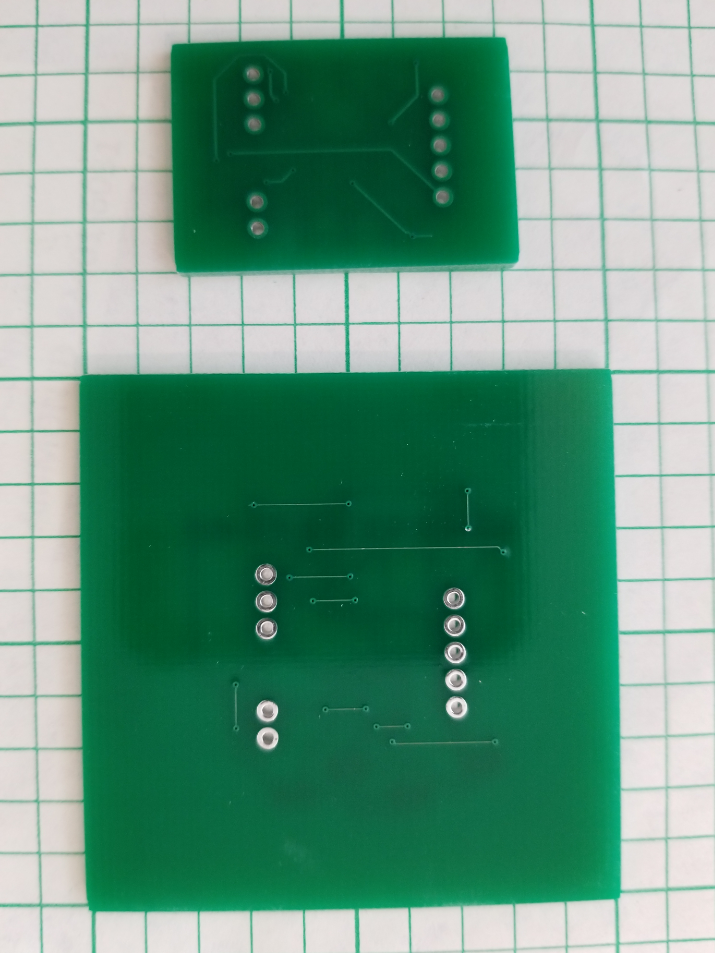
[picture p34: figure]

Figure 2 Comparison of largest mixer PCB outline with the smallest mixer PCB outline designed in ECEN 250 S20.

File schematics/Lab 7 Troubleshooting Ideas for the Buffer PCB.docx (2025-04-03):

Lab 7 Troubleshooting Ideas for the Buffer PCB

Purposes of the PCB and soldering:

- Make good intended electrical connections between the mother board and the components on the buffer PCB.
- The PCB provides mechanical structure to hold the components in place, traces to rout the electrical connections, pads to solder to, and a solder mask to help prevent solder from flowing where it should not go.
- The solder makes robust electrical connections between the pads on the PCB and the components.

Problems that can arise:

- The traces on the PCB rout electrical connections to the wrong places.
- The components are placed in the wrong orientation (applies to the op amp IC) or in the wrong spot (applies to the resistors).
- Problems with soldered connection:
  - Does not make the connection (open)
  - Makes an intermittent connection (typically from a cold soldered joint – the pins were not hot enough, solder was melted on the iron rather than on the pin and pads, and/or flux was not used.)
  - Make unintended connections (shorts from solder bridges)

# Procedures to following if the buffer PCB is not working:

With components soldered on the PCB and the buffer PCB is placed on the bench (i.e., it is not inserted in the motherboard)

Check Op Amp orientation:

Is the beveled side of the op amp on the same side as R1 and R2? If it is in backward and you have applied power to the board, the Op Amp is ruined and needs to be replaced.

Check Continuity using a DMM:

This will find opens in the nets. When probing a pin on the LF347 for continuity, also, prob adjacent pins to make sure there is not a solder bridge to either one (i.e., a short).

For header pins, touch the pin on the bottom side of the PCB (don't touch the solder or the pad)

For LF347 pins, touch the top of the pin (not the solder or pad)

- Between Header GND Pin and LF347 Pin 3
- Between Header GND Pin and LF347 Pin 12
- Between Header V+ Pin and LF347 Pin 4
- Between Header V- Pin and LF347 Pin 11
- Between Header Lout Pin and LF347 Pin 1
- Between Header Rout Pin and LF347 Pin 14
- Between LF347 Pin 2 and one side of R1
- Between LF347 Pin 2 and one side of R2
- Between LF347 Pin 13 and one side of R3
- Between LF347 Pin 13 and one side of R4

Check Resistance using a DMM:

- Between Header Lin and Header Lout should be 40 kΩ
- Between Header Rin and Rout should be 40 kΩ
- Between Header Lin and LF347 Pin 2 should be 10 kΩ
- Between Header Lout and LF347 Pin 2 should be 30 kΩ
- Between Header Rin and LF347 Pin 13 should be 10 kΩ
- Between Header Rout and LF347 Pin 13 should be 30 kΩ

Set up the function generator and Oscilloscope using a known good Buffer PCB. You can borrow one from the Lab Assistant. This ensures that you have the connections correct.

Do not "hot swap" your PCB into the motherboard. That is, make sure the power to the motherboard is turned off and the charge on the capacitors drained off. The power LEDs will be off when the capacitors are drained.
